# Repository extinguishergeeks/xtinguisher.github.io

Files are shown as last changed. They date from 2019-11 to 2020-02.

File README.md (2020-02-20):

# xtinguisher.github.io

## Welcome

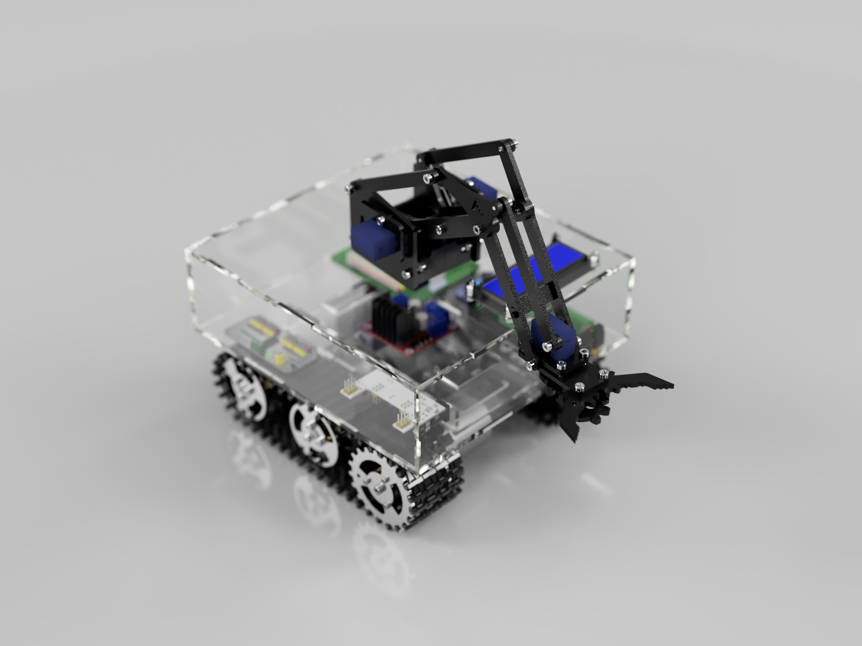
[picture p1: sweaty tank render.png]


This git repository serves as a platform to us to document our tank. We are working on a bomb disposal robot tank that helps war torn civilians safely and easily defuse bombs without calling in EOD teams

### Problem background

After a war, there are many unexploded bombs or mines leftover that may threaten civilian lives. So, we decided to conceive a way for civilians to safely dispose of bombs with minimal training.

### Problem statement

“How are we able to assist with bomb disposal”

### Main features of the tank

- Robotic arm with 4 Degrees of freedom (DOF)
- Modular housing and design
- Camera mounted on the arm for larger field of view during operation
- WiFi web control for easier training… control from phone instead of specialised panel

### Documentations
<a href="mechanical documentation.md">Mechanical Documentations</a>

The poster that provides an overview of our project: <a href="presentation poster.pptx">Poster</a>

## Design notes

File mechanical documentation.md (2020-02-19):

# Extinguisher Geeks [Home](homepage.md)     [About](README.md) (mechanical documentation)

## Mechanical documentation

### Tank
The tank is a fully modular design for easy assembly, use and fabrication. The fully rendered image of the tank can be seen below.



### housing
The housing of the tank is made from pieces of 3mm acrylic plates glued together. The structure is a monocoque design which helps to save weight, thus increasing the protablility and reducing the cost of production. Chloroform, a type of acrylic glue, is applied to finger joints of the each plate to reinforce the integrity of the joint. 

### Mounting Structure
A mounting structure is also produced, with the purpose of mounting the housing to the tracks. As the housing have a larger footprint than the track base itself, the mounting platform is desgined in a way that it serves as an adaptor to compensate the difference in footprint. In terms of frabication and assembly, it is done in a similar fashion to the housing. The image of the mounting structure can be seen below.

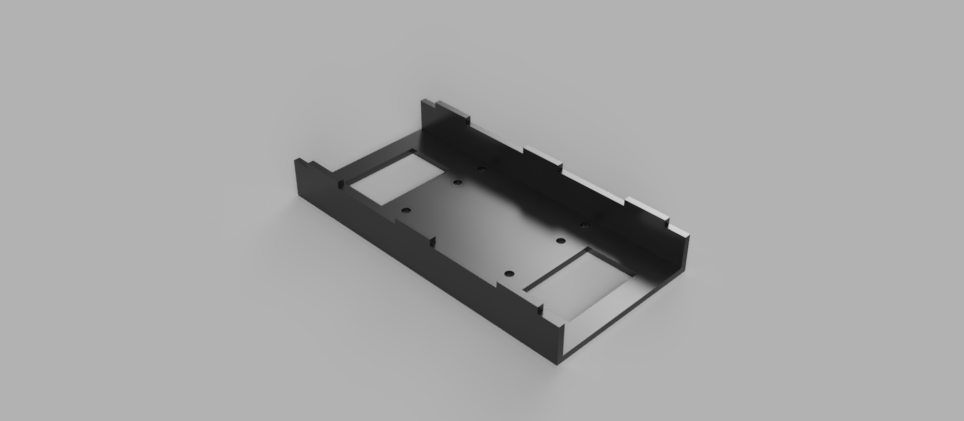
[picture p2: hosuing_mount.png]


### Robot Arm
The robot arm is a arm kindly provided by our lecturer. It has 4 degrees of freedom. It is controlled by servo motors and linkages. It has 4 Degrees of freedom. The design is also open source and readily available.

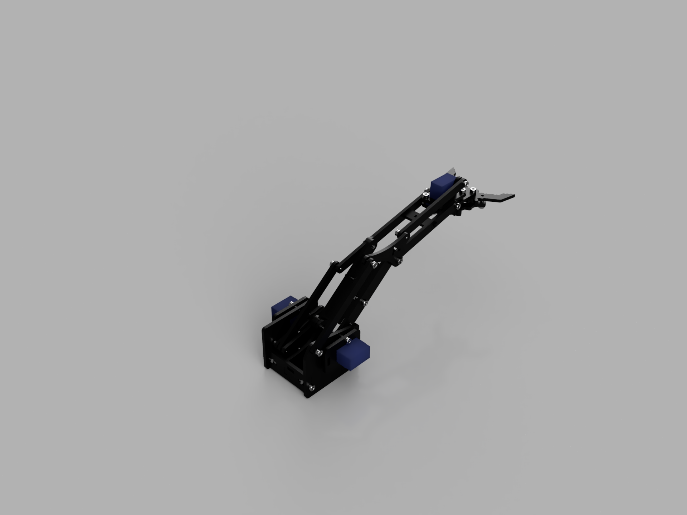
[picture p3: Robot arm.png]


### ESP CAM mount
The ESP CAM mount is used to mount the ESP camera via transition tight fit (H7/k6). It is glued to the robot arm and it is made from a single part. The image of the ESP CAM mount can be seen below.

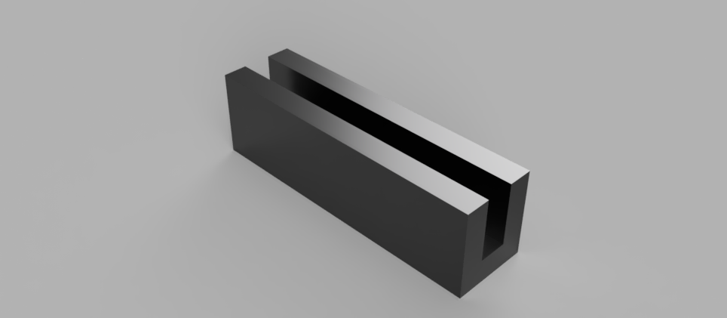
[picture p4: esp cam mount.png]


### Methodology to determine the effectiveness of the tank at carrying out it's intended purposes

- Measure the time taken to defuse bomb to determine the viability of the prototype through empirical means
- 2 groups of people - EOD team as control and normal civilians
- If normal civilians can successfully defuse the bomb within double the time taken for the EOD team then the tank is successful
- It may be difficult to determine via mathematical analysis due to the involvement of human factors

### Motor Torque calculations
The torque calculations can be found on our github  at: <a href="Tank Calculations.pptx">Tank Calculations.pptx</a>

### Mechanical CAD drawings
The mechanical CAD drawings can be found on our github at: 

f3d file format (for part files): <a href="tank fusion 360 part files.zip"> tank fusion 360 part files.zip</a>

f3z file format (for sub assemblies): <a href="tank fusion 360 sub assembly.zip">tank fusion 360 sub assembly.zip</a>

f3z file format (for full assembly): <a href="tank fusion 360 full assembly.zip">tank fusion 360 full assembly.zip</a>

STEP file format: <a href="Tank STEP files.zip"> Tank STEP files.zip</a>

### Robot arm CAD drawings
The CAD drawing for the arm can be found at <a href="https://www.thingiverse.com/thing:993759">MeArm</a>

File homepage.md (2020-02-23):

# Extinguisher Geeks [Home]()     [About](README.md)       [Tutorial](tutorial.md)

Reference for Week1:
  * [Github desktop] https://desktop.github.com/
  * [Git] https://git-scm.com/
  * [Tutorial On How to use Git] https://www.youtube.com/watch?v=pwOwl2N2fmk
  
Reference for Week2：
  * [Micropython] https://micropython.org
  * [Micropython microbit] https://microbit-micropython.readthedocs.io/en/latest/micropython.html
  * [CodeWithMu] https://codewith.mu/en/about

Reference for Week3:
  * [Tanks] https://en.wikipedia.org/wiki/Tank
  * [Tiles of Tank(tracked vechicles)] https://en.wikipedia.org/wiki/Sprocket
  
 Reference for Week4:  
  * [ESP32] http://esp32.net/
  * For breadboard, use only red wire for 5V. To prevent confusion during fault detection.
  * [Step1:Building Firmware] https://learn.adafruit.com/building-and-running-micropython-on-the-esp8266/build-firmware
  * [Step2:Flash Fimware] https://learn.adafruit.com/building-and-running-micropython-on-the-esp8266/flash-firmware
  
 
 
 * [How to use a Bi-directional logic level converter
 ]  https://learn.sparkfun.com/tutorials/bi-directional-logic-level-converter-hookup-guide/all
 
 *[] https://dronebotworkshop.com/dc-motors-l298n-h-bridge/

1:knowing that you are going to use the esp32.

2.go to websites where you can choose the model of esp32 which is suitable and affordable for your usage.

2a.After purchasing the esp32

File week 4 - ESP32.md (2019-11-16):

# Extinguisher Geeks [Home](homepage.md)     [About]() [Tutorial](week 4 - ESP32.md)
### setting up the ESP 32

The ESP 32 is a microcontroller which offers wifi capacability. This blog will show how to flash and set up micropython into the ESP 32.

First you need to download python 3. Remember to select add to PATH when installing python 3. You can find python at https://www.python.org . 

Next, download the file needed to flash micropython into ESP 32 at https://micropython.org/download#esp32

Next open up command prompt (CMD) and run as administor.

In the CMD, type 

    pip3 install esptool

After installation, then type this command

    esptool.py --port /dev/ttyUSB0 erase_flash

Remember to change the port setting to match the port you are using for the ESP 32

After, that, open the folder that has the firmware for the ESP 32. Run CMD on the folder and type in the following command

    esptool.py --chip esp32 --port /dev/ttyUSB0 write_flash -z 0x1000 esp32-20180511-v1.9.4.bin

Remember to change the port setting to match the port you are using for the ESP 32

Next, type in this command

    pip install rshell

After that, type

    rshell

This will open up the rshell command line interface in your CMD

Next,visit https://micropython.org/download#esp32 and download the correct firmware file for your board.

Before writting the firmware,we have to erase the flash memory of esp32, check your port number again. In this case i will use COM3

    esptool --chip esp32 --port COM3 erase_flash

After the firmware is being installed, the device will reboot and then we are ready start our first MicroPython program.
esptool --chip esp32 --port COM3 --baud 460800 write_flash -z 0x1000    

    esptool --chip esp32 --port COM3 --baud 460800 write_flash -z 0x1000 esp32spiram-20190529-v1.11.bin

Next connect the MicroPython repl using rshell
    
    rshell -p COM3 repl

And then, your Esp32 is ready to use, enjoy with your MicroPython.

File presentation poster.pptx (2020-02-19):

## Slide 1

TEAM EXTINGUISHERS GEEKS
BOMB DISPOSAL TANK

Background
After war, there are many unexploded bombs or mines leftover that threaten civilian lives. So, we conceived a way for civilians to safely dispose of bombs with minimal training

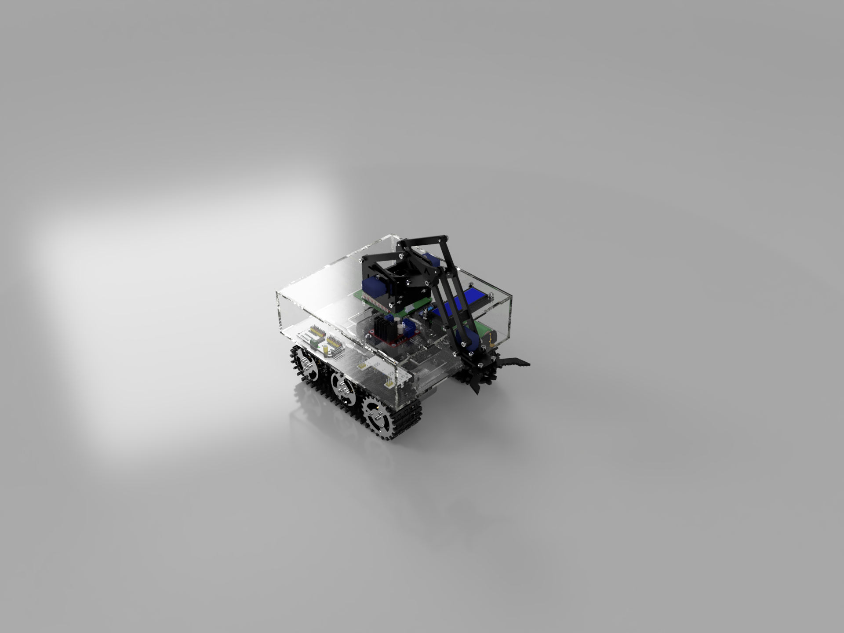
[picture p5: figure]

Problem Statement
How are we able to assist with bomb disposal?

Product developed:

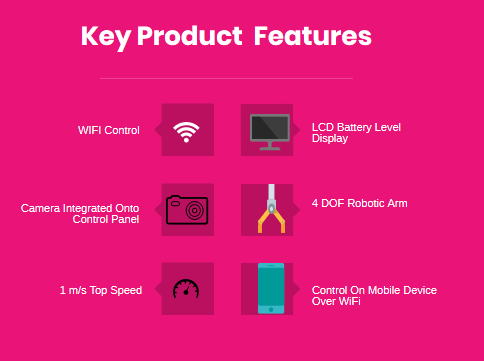
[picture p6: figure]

BOMB DISPOSAL ROBOT
MODULAR DESIGN
EASY TO FABRICATE, ASSEMBLE AND USE

Product images

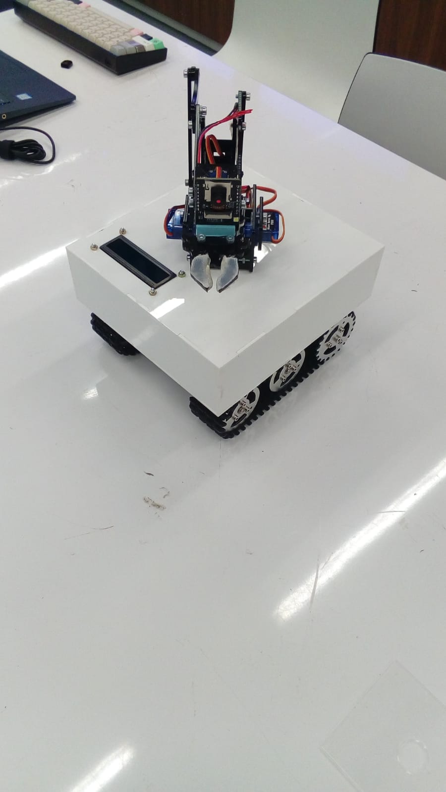
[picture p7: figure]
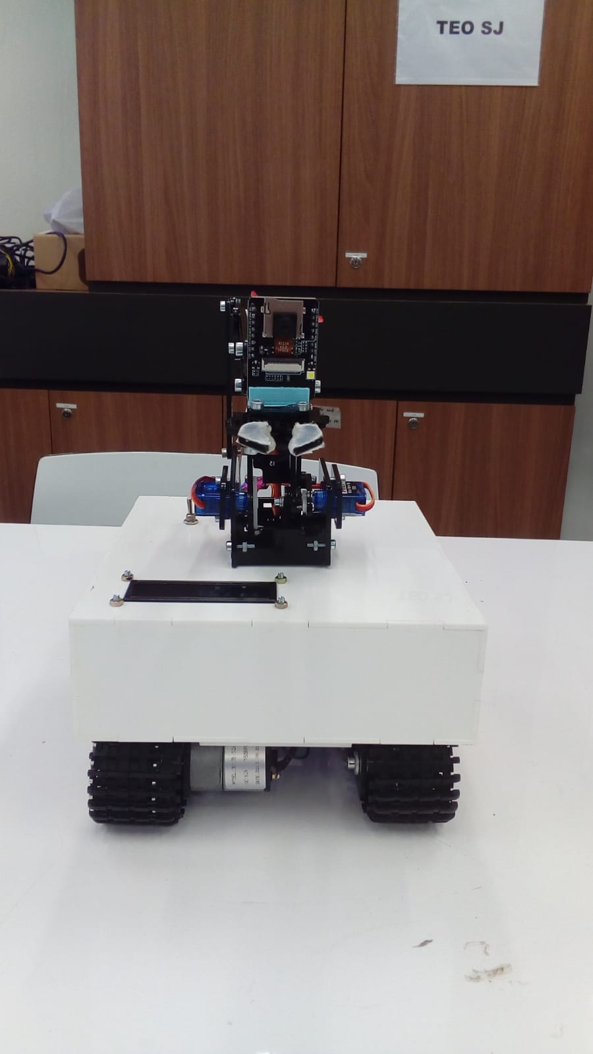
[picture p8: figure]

FULLY ASSEMBLED CAD MODEL

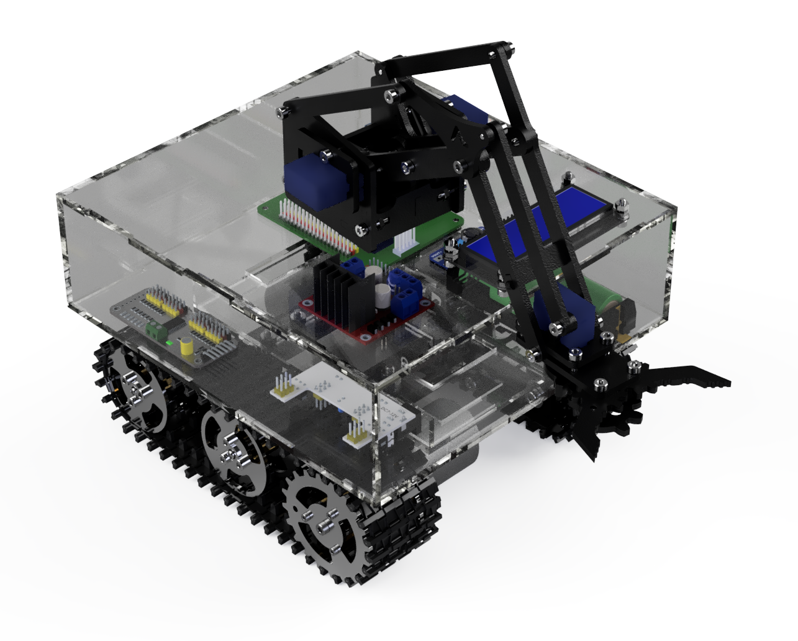
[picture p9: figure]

Team Members
Ang Kiat Wan Sorenson
Aeronautical Engineering
Jia Nan
Computer Engineering
Syed Shahul Hameed
Energy Systems and Management
Yeo Ying Shen Reynard
Mechanical Engineering

Website: https://github.com/sorenson523/xtinguisher.github.io

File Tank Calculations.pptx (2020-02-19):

## Panzerkampfwagen robot tank EA tank Project motor calculations

By: team extinguisher geeks

## Assumptions and Constants

- No air resistance
- surface friction coefficient of poor concrete µ= 0.022
- Radius of wheel r= 0.029m
- All calculations are done with SI units
- Target Vmax = 1.0 m/s
- Target t_a =2secs
- Max incline = 10 degrees
- Acceptable time to Vmax: 1 to 5 seconds
- Constant torque generated by motor
- Constant position of centre of gravity
- Resistance factor R_f =1.1
- Number of wheels = 6
- Number of drive wheels = 2
- Static coefficient is 0.3 (plastic and concrete)
- Number of motors = 2

## Free body diagrams (flat ground)

Rn

Ft

Tw

Fs

Ft

mg

## Free body diagrams (on 10 degree slope)

Rn

Ft

Ft

Tw

mg sin 10

Fs

a = 10 deg

mg

mg cos 10

## Min Torque Calculations (Part 1)

F_(SF) =μ_(CF) R_n
F_(SF) =0.022×1.5×9.81
F_(SF) =0.324N
F_(GR) =mgsina
F_(GR) =1.5×9.81×sin10°
F_(GR) =2.555N
F_a =ma
F_a =1.5×(1.0÷2)
F_a =0.75N

(Surface friction)

(Grade resistance)

(Acceleration force)

## Min Torque Calculations (Part 2)

F_T =ΣF_n
F_T =F_(SF) +F_(GR) +F_a
F_T =0.324+2.555+0.75
F_T =3.629N
T_w =F_T rR_f
T_w =3.629×0.029×1.1
T_w =0.115Nm

(Sum of forces)

(Min torque needed)

## C.G distribution diagram

Motion direction

Reference datum A

Rn3

Rn1 – driving wheels: 10% from reference datum
CG: 50% from reference datum
Rn2 – idler wheels: 90% from reference datum
Height of CG: 50% from reference height
Rn3 – idler wheels: 50% from reference datum

Rn2

Rn1

0.5

0.9

0.1

CG

Reference height h

0.5

## Normal force calculations

Taking moments from reference datum A…
ΣM_A =0
0.1R_(n1) −0.5CG+0.9R_(n2) +0.5R_(n3) =0
0.1R_(n1) +0.9R_(n2) +0.5R_(n3) =7.358
R_(n1) +9R_(n2) +5R_(n3) =73.58
ΣF_y =0
R_(n1) +R_(n2) +R_(n3) −14.715=0

## Normal force calculations

Since the C.G is at 50% from datum A and reference height h and the wheels are spaced equally apart…
R_(n1) =R_(n2) =R_(n3) =14.715÷6=2.453N

## Max Tractive Torque Calculations

T_(maxT) =R_(n1) rμ_s
T_(maxt) =2.453×0.029×0.3×2
T_(maxT) =0.0427Nm

## Recommended torque and rpm

Based on my calculations, I recommend the minimum motor torque is 0.115Nm, maximum motor torque is 0.0427Nm and my recommend rpm is 350 rpm

## Calculations (Tw vs t)

F_T =F_s +F_(GR) + ma
F_T =3.305+1.5a
T_T =F_T r
T_T =0.029(3.305+1.5a)
T_T =0.0958+0.0435a
T_w =0.0958+0.0435t^(−1)

## Calculations (Tw vs t)

At t=1s
T_w =0.0958 +0.0435t^(−1)
T_w =0.0958+0.0435(1)^(−1)
T_w =0.139Nm
At t=2s
T_w =0.0958+0.0435t^(−1)
T_w =0.0958+0.0435(2)^(−1)
T_w =0.118Nm

## Tw vs t graph

T_(w(min)) =0.115Nm

T_w =0.0958+0.0435t^(−1)

T_(maxT) =0.0427Nm

## Significance of the graph

The graph is to determine the suitable time to maximum speed without causing problems such as insufficient grip and insufficient wheel motor torque.

## Conclusions based on calculations

Rated torque = 4.0 kg cm *2 = 0.784Nm
Minimum torque = 0.115Nm
Thus, I can conclude that the motor is capable of moving the tank. However, skidding issues may occur as the motor rated torque is way higher than the MTT.

## The End

## References

https://www.aliexpress.com/item/32876428827.html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,searchweb201602_6,searchweb201603_55

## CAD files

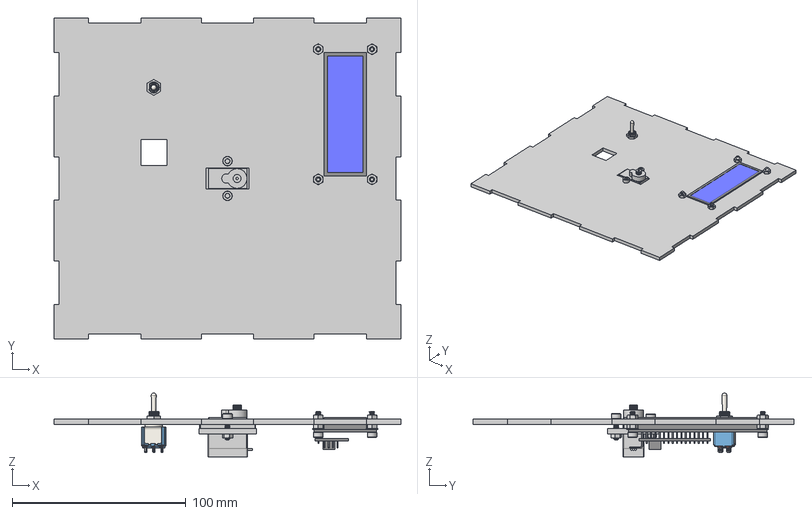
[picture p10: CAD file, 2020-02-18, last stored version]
top housing plate assembly v5.step
200.0 x 185.0 x 36.9 mm
top eee plate
91290A117 x 6
servo mounting plate
FS09R_Servo_Motor
94150A325 x 10
5649agbx408 - 5000 PCB
M6 panel nut
LGDehome IIC-I2C-TWI LCD 1602
ISO 7089 M3 Plain Flat washer x 4

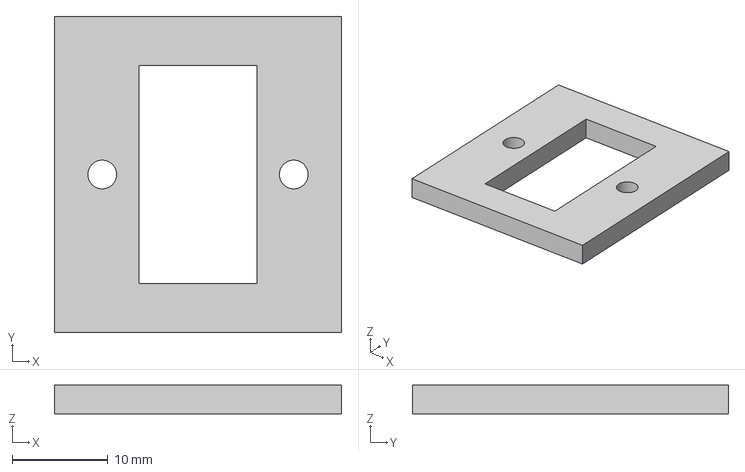
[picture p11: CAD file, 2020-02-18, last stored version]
servo mounting plate v2.step
30.0 x 33.0 x 3.00 mm

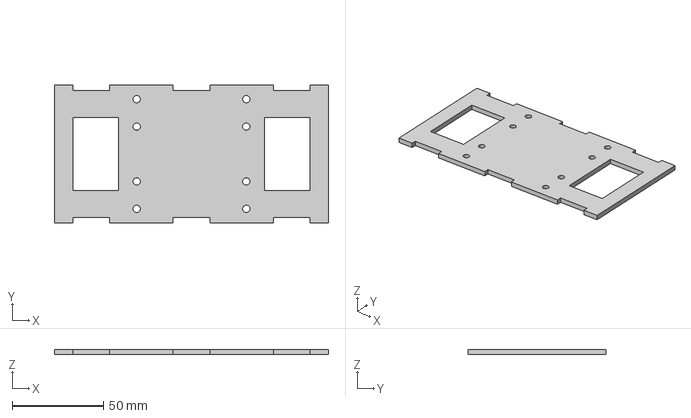
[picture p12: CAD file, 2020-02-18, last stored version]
base mounting plate v7.step
150.0 x 75.5 x 3.00 mm

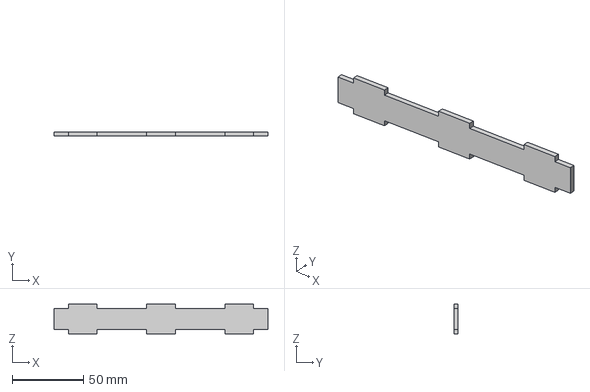
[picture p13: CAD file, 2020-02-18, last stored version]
mounting side plate v2.step
150.0 x 3.00 x 21.0 mm

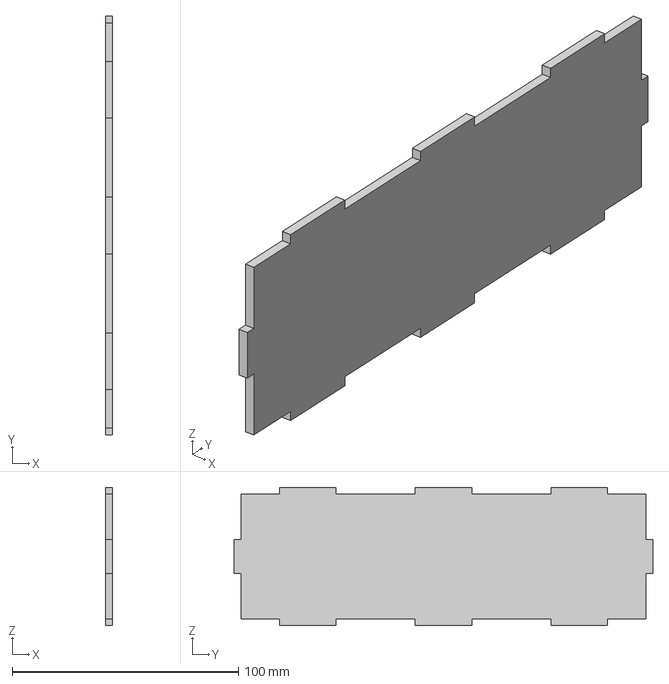
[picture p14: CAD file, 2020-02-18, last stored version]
tank housing fwd and aft plate v5.step
3.00 x 185.0 x 61.0 mm

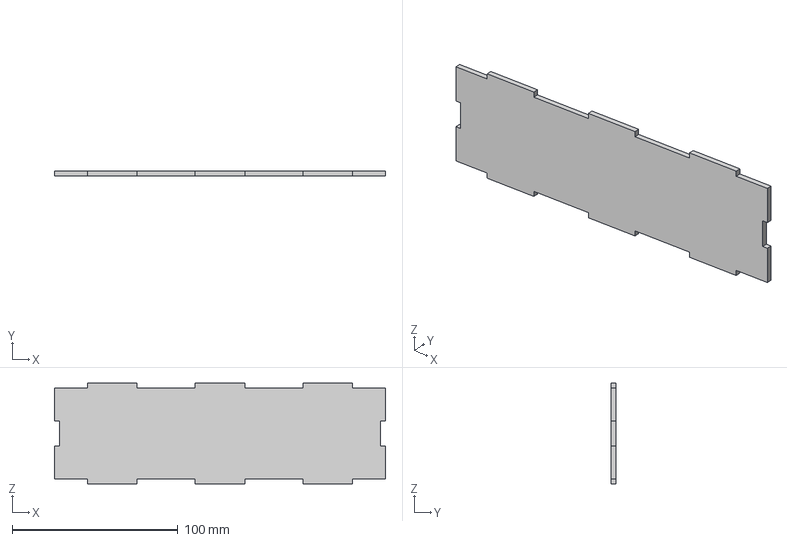
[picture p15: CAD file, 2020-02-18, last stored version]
tank cover side plate v10.step
200.0 x 3.00 x 61.0 mm

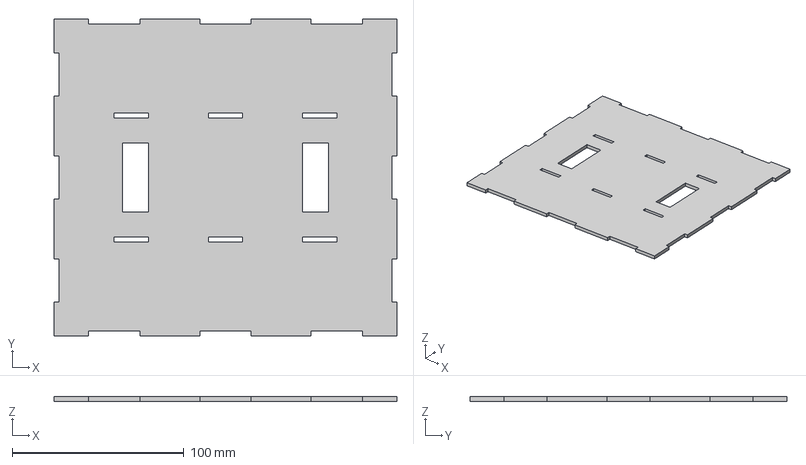
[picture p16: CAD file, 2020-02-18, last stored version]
base housing plate v7.step
200.0 x 185.0 x 3.00 mm

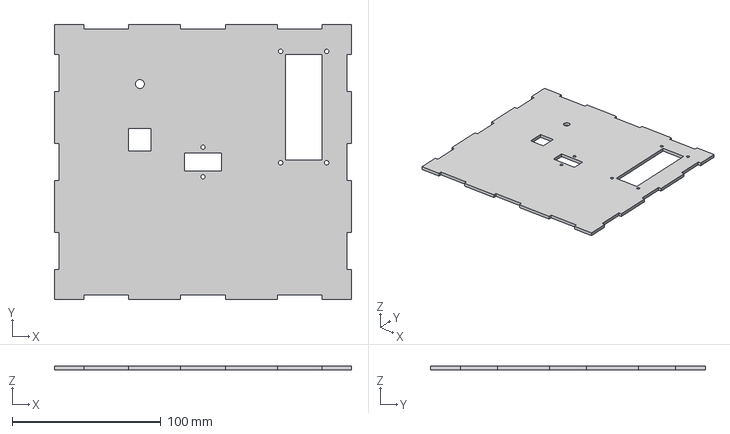
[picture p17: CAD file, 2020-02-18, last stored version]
top housing plate v7.step
200.0 x 185.0 x 3.00 mm

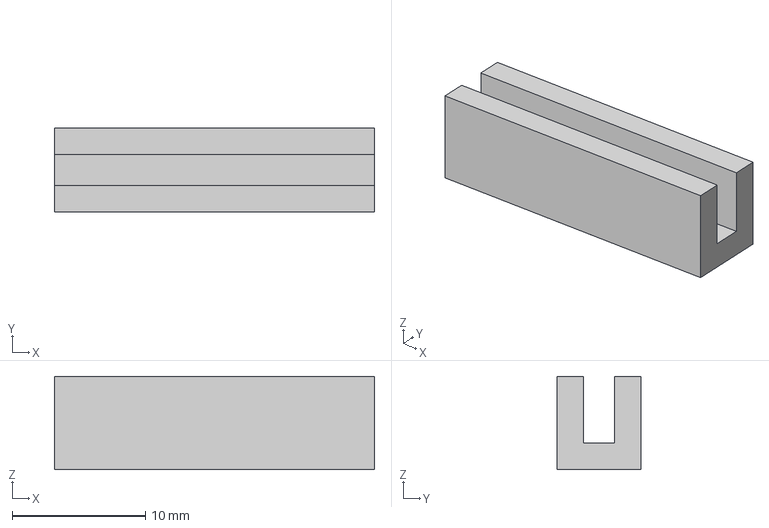
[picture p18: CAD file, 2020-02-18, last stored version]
esp cam mount v1.step
24.0 x 6.30 x 7.00 mm

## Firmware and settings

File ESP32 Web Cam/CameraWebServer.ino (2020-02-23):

#include "esp_camera.h"
#include <WiFi.h>

//
// WARNING!!! Make sure that you have either selected ESP32 Wrover Module,
//            or another board which has PSRAM enabled
//

// Select camera model
//define CAMERA_MODEL_WROVER_KIT
//#define CAMERA_MODEL_ESP_EYE
//#define CAMERA_MODEL_M5STACK_PSRAM
//#define CAMERA_MODEL_M5STACK_WIDE
#define CAMERA_MODEL_AI_THINKER

#include "camera_pins.h"

const char* ssid = "EaExtin";
const char* password = "";

// ip address
IPAddress local_IP(192, 168, 22, 10);
// ip gatewat
IPAddress gateway(192, 168, 22, 1);

IPAddress subnet(255, 255, 255, 0);
void startCameraServer();

void setup() {
  Serial.begin(115200);
  Serial.setDebugOutput(true);
  Serial.println();

  camera_config_t config;
  config.ledc_channel = LEDC_CHANNEL_0;
  config.ledc_timer = LEDC_TIMER_0;
  config.pin_d0 = Y2_GPIO_NUM;
  config.pin_d1 = Y3_GPIO_NUM;
  config.pin_d2 = Y4_GPIO_NUM;
  config.pin_d3 = Y5_GPIO_NUM;
  config.pin_d4 = Y6_GPIO_NUM;
  config.pin_d5 = Y7_GPIO_NUM;
  config.pin_d6 = Y8_GPIO_NUM;
  config.pin_d7 = Y9_GPIO_NUM;
  config.pin_xclk = XCLK_GPIO_NUM;
  config.pin_pclk = PCLK_GPIO_NUM;
  config.pin_vsync = VSYNC_GPIO_NUM;
  config.pin_href = HREF_GPIO_NUM;
  config.pin_sscb_sda = SIOD_GPIO_NUM;
  config.pin_sscb_scl = SIOC_GPIO_NUM;
  config.pin_pwdn = PWDN_GPIO_NUM;
  config.pin_reset = RESET_GPIO_NUM;
  config.xclk_freq_hz = 20000000;
  config.pixel_format = PIXFORMAT_JPEG;
  //init with high specs to pre-allocate larger buffers
  if(psramFound()){
    config.frame_size = FRAMESIZE_UXGA;
    config.jpeg_quality = 10;
    config.fb_count = 2;
  } else {
    config.frame_size = FRAMESIZE_SVGA;
    config.jpeg_quality = 12;
    config.fb_count = 1;
  }

#if defined(CAMERA_MODEL_ESP_EYE)
  pinMode(13, INPUT_PULLUP);
  pinMode(14, INPUT_PULLUP);
#endif

  // camera init
  esp_err_t err = esp_camera_init(&config);
  if (err != ESP_OK) {
    Serial.printf("Camera init failed with error 0x%x", err);
    return;
  }

  sensor_t * s = esp_camera_sensor_get();
  //initial sensors are flipped vertically and colors are a bit saturated
  if (s->id.PID == OV3660_PID) {
    s->set_vflip(s, 1);//flip it back
    s->set_brightness(s, 1);//up the blightness just a bit
    s->set_saturation(s, -2);//lower the saturation
  }
  //drop down frame size for higher initial frame rate
  s->set_framesize(s, FRAMESIZE_QVGA);

#if defined(CAMERA_MODEL_M5STACK_WIDE)
  s->set_vflip(s, 1);
  s->set_hmirror(s, 1);
#endif

  WiFi.begin(ssid, password);

  while (WiFi.status() != WL_CONNECTED) {
    delay(500);
    Serial.print(".");
  }
  Serial.println("");
  Serial.println("WiFi connected");

  startCameraServer();

  Serial.print("Camera Ready! Use 'http://");
  Serial.print(WiFi.localIP());
  Serial.println("' to connect");
}

void loop() {
  // put your main code here, to run repeatedly:
  delay(10000);
}

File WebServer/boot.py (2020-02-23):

try:
  import usocket as socket
except:
  import socket
  

import network
import machine
from machine import Pin, ADC, PWM, I2C
import math
import time
import servo
import esp
esp.osdebug(None)

import gc
AIN1 = Pin(15,Pin.OUT)
AIN2 = Pin(2,Pin.OUT)
BIN1 = Pin(0,Pin.OUT)
BIN2 = Pin(4,Pin.OUT)

PWMPinA = PWM(Pin(16), freq = 980)
PWMPinB = PWM(Pin(17), freq = 980)

i2c=I2C(-1, scl=Pin(22), sda=Pin(21))
servo = servo.Servos(i2c)
servo.position(0, degrees=75)
servo.position(1, degrees=75)
servo.position(2, degrees=90)
servo.position(3, degrees=90)
def ModeStop():
    AIN1.off()
    AIN2.off()
    BIN1.off()
    BIN2.off()
    
def ModeForward():
    AIN1.on()
    AIN2.off()
    BIN1.on()
    BIN2.off()
    
def ModeBackward():
    AIN1.off()
    AIN2.on()
    BIN1.off()
    BIN2.on()
    
def ModeRight():
    AIN1.on()
    AIN2.off()
    BIN1.off()
    BIN2.on()
    
def ModeLeft():
    AIN1.off()
    AIN2.on()
    BIN1.on()
    BIN2.off()
    
def OpenClose():
    servo.position(0,0)
def OpenClose1():
    servo.position(0,180)   
def ForBack():
    servo.position(1,0)
def ForBack1():
    servo.position(1,90)
def ForBack2():
    servo.position(1,180)    
def UpDown():
    servo.position(2,0)
def UpDown1():
    servo.position(2,90)
def UpDown2():
    servo.position(2,180)    
def LeftRight():
    servo.position(3,0)
def LeftRight1():
    servo.position(3,90)
def LeftRight2():
    servo.position(3,180)
    
gc.collect()

ssid = 'EaExtin'
password = ''
robot_state = "Stop"

ap = network.WLAN(network.AP_IF)
ap.active(True)
ap.config(essid=ssid, password=password)
ap.ifconfig(('192.168.22.1', '255.255.255.0', '192.168.22.1', '8.8.8.8'))


while ap.active() == False:
  pass

print('Connection successful')
print(ap.ifconfig())



def web_page():
  
  html = """
  <html>
  <head> 
  <title>ESP Web Server</title> <meta name="viewport" content="width=device-width, initial-scale=1">
  <link rel="icon" href="data:,"> 
  <style>
  html{font-family: Helvetica; display:inline-block; margin: 0px auto; text-align: center;}
  h1{color: #0F3376; padding: 2vh;}p{font-size: 1.5rem;}
  .button{display: inline-block; background-color: #e7bd3b; border: none; 
  border-radius: 4px; color: white; padding: 16px 40px; 
  text-decoration: none; font-size: 30px;
  margin: 2px; cursor: pointer;}
  .buttonStop{background-color: red;}
  .rotateimg180{-webkit-transform:rotate(180deg);
  -moz-transform: rotate(180deg);
  -ms-transform: rotate(180deg);
  -o-transform: rotate(180deg);
  transform: rotate(180deg);}
   </style>
  <script src=\"https://ajax.googleapis.com/ajax/libs/jquery/3.3.1/jquery.min.js\"></script>
  <script src="https://obniz.io/js/jquery-3.2.1.min.js"></script>
  <script src="https://unpkg.com/obniz@3.3.0/obniz.js"></script>
  </head>
  <body> 
  <h1>ESP Web Server</h1>
  <img class="stream" src=http://192.168.22.2:81 class="rotateimg180"/stream>
  <p>Robot state: <strong>""" + robot_state + """</strong></p>
  <p><a href="/?robot=stop"><button class="button buttonStop">STOP</button></a></p>
  <p><a href="/?robot=forward"><button class="button">FORWARD</button></a></p>
  <p><a href="/?robot=backward"><button class="button">BACKWARD</button></a></p>
  <p><a href="/?robot=right"><button class="button">RIGHT</button></a></p>
  <p><a href="/?robot=left"><button class="button">LEFT</button></a></p>
  <p>Open and Close</p>
  <p><a href="/?Req1=0\"><button class="button">0 degrees</button></a>
     <a href="/?Req1=90\"><button class="button">45 degrees</button></a>
  <p>Up and Down</p>   
  <p><a href="/?Req2=0\"><button class="button">0 degrees</button></a>
     <a href="/?Req2=90\"><button class="button">90 degrees</button></a>
     <a href="/?Req2=180\"><button class="button">180 degrees</button></a></p>
  <p>Forward and Backward</p>   
  <p><a href="/?Req3=0\"><button class="button">0 degrees</button></a>
     <a href="/?Req3=90\"><button class="button">90 degrees</button></a>
     <a href="/?Req3=180\"><button class="button">180 degrees</button></a></p>
  <P>Left and Right</p>  
  <p><a href="/?Req4=0\"><button class="button">0 degrees</button></a>
     <a href="/?Req4=90\"><button class="button">90 degrees</button></a>
     <a href="/?Req4=180\"><button class="button">180 degrees</button></a></p>     
  </body>
  </html>"""
  return html

s = socket.socket(socket.AF_INET, socket.SOCK_STREAM)
s.bind(('', 80))
s.listen(5)

while True:
  conn, addr = s.accept()
  print('Got a connection from %s' % str(addr))
  request = conn.recv(1024)
  request = str(request)
  print('Content = %s' % request)
  robot_stop = request.find('/?robot=stop')
  robot_forward = request.find('/?robot=forward')
  robot_backward = request.find('/?robot=backward')
  robot_right = request.find('/?robot=right')
  robot_left = request.find('/?robot=left')
  oc_0 = request.find('/?Req1=0')
  oc_90 = request.find('/?Req1=90')
  up_0 = request.find('/?Req2=0')
  up_90 = request.find('/?Req2=90')
  up_180 = request.find('/?Req2=180')
  fb_0 = request.find('/?Req3=0')
  fb_90 = request.find('/?Req3=90')
  fb_180 = request.find('/?Req3=180')
  lr_0 = request.find('/?Req4=0')
  lr_90 = request.find('/?Req4=90')
  lr_180 = request.find('/?Req4=180')
  if oc_0 == 6:
    OpenClose()
  if oc_90 == 6:
    OpenClose1()
  
  if up_0 == 6:
    UpDown()
  if up_90 == 6:
    UpDown1()
  if up_180 == 6:
    UpDown2()
  if fb_0 == 6:
    ForBack()
  if fb_90 == 6:
    ForBack1()
  if fb_180 == 6:
    ForBack2()
  if lr_0 == 6:
    LeftRight()
  if lr_90 == 6:
    LeftRight1()
  if lr_180 == 6:
    LeftRight2()
  if robot_stop == 6:
    print('robot stopping...')
    robot_state = "Stop"
    ModeStop()
  if robot_forward == 6:
    print('robot advancing forward...')
    robot_state = "Forward"
    ModeForward()
  if robot_backward == 6:
    print('robot retreating backward...')
    robot_state = "Backward"
    ModeBackward()
  if robot_right == 6:
    print('robot turning right...')
    robot_state = "Right"
    ModeRight()
  if robot_left == 6:
    print('robot turning left...')
    robot_state = "Left"
    ModeLeft()
  response = web_page()
  conn.send('HTTP/1.1 200 OK\n')
  conn.send('Content-Type: text/html\n')
  conn.send('Connection: close\n\n')
  conn.sendall(response)
  conn.close()
